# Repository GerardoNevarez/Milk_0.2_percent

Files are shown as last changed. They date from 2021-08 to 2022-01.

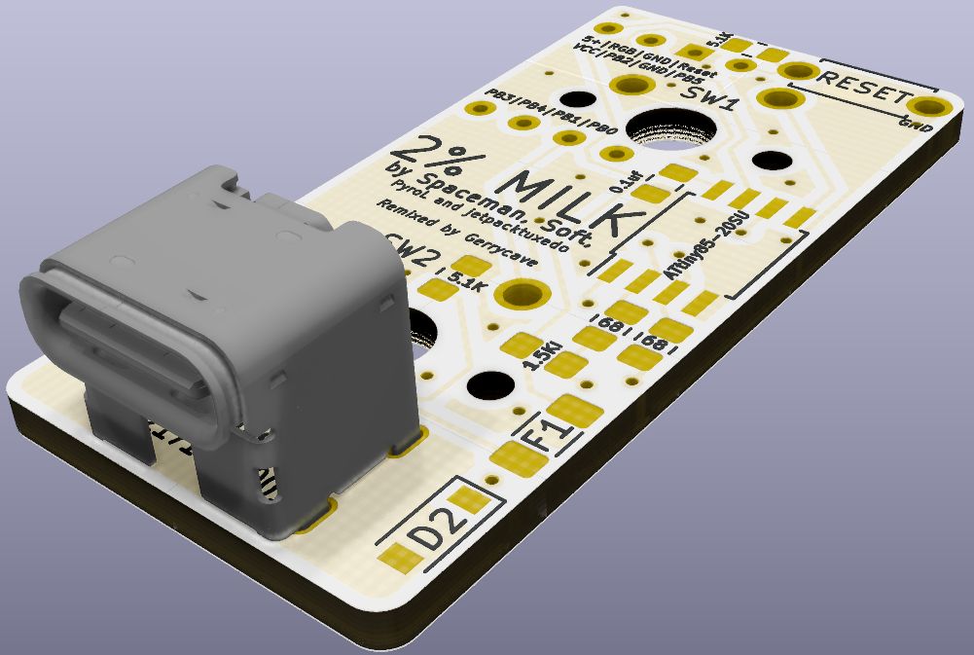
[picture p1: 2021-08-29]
milk-3D-render.jpg

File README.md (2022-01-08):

# Milk 0.2 percent

Remix from the [2% Milk](https://github.com/Spaceboards/SpaceboardsHardware/blob/master/Keyboards/2%25%20Milk/milk_kicad.zip) by Spaceman

# BOM

- 1 - Molex 2171800001 USB-C connector [Mouser](https://www.mouser.com/ProductDetail/Molex/217180-0001?qs=DRkmTr78QAS4XYOWSgPndA%3D%3D)
- 1 - SOIC-8 ATtiny85 - [ATTINY85-20SU](https://www.mouser.com/ProductDetail/Microchip-Technology-Atmel/ATTINY85-20SU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) 
- 1 - 0805 0.1uF ceramic cap
- 1 - 0805 4.7uF ceramic cap
- 1 - 0805 1.5k omh resistor
- 2 - 0805 5.1k omh resistors
- 2 - 0805 68 omh resistors
- 1 - 1206 500ma PolyFuse
- 2 - 0805 3.6V Zener diodes
- 1 - (optional) 6x3mm THT temporary push switch (Reset)
- 2 - (optional) 1515 RGB leds - SK6805-EC-15 [Adafruit](https://www.adafruit.com/product/4492)

Use the front and back PCB renders, to locate the location for the parts

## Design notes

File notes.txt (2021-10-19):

1-RST button
2-PB3 header
3-PB4 header
4-GND - rst button, SW1,SW1 Pad2 NW, RGB header
5-SW1-pad1-NE
6-SW2-pad1-NE
7-RGB header
8-5V RGB header

switch holes  2/1.3mm

 1.524  / 0.8128
 
 0.762  mm sockets

 1.397

 36.69   17.42 plate hole
 
 42.55   23    box holes

5mm  to window
7.95   window height

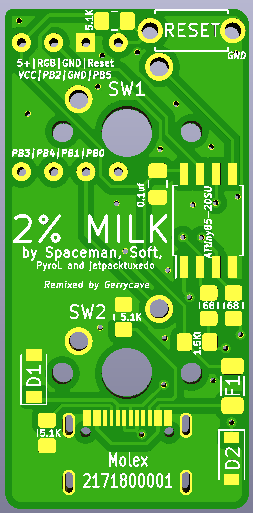
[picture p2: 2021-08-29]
milk-front.png

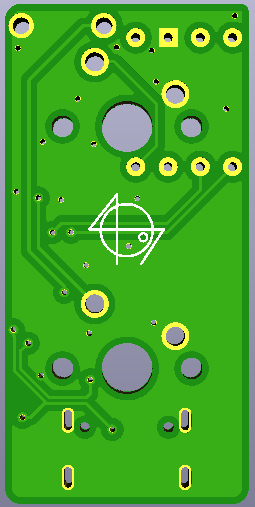
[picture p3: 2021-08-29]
milk-back.png

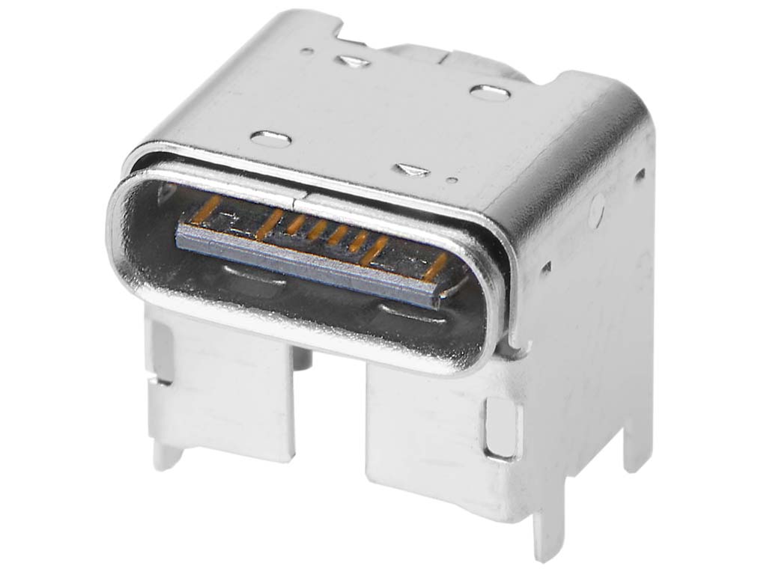
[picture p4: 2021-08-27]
Molex_data/2171800001_hires.jpg

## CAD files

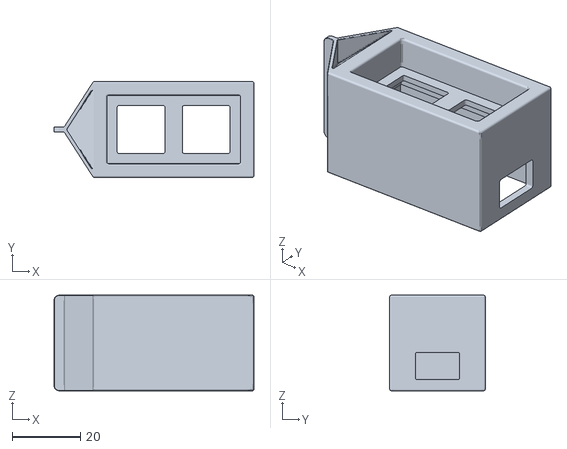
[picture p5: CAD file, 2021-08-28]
milk_case.stl
58.6 x 28.0 x 28.0

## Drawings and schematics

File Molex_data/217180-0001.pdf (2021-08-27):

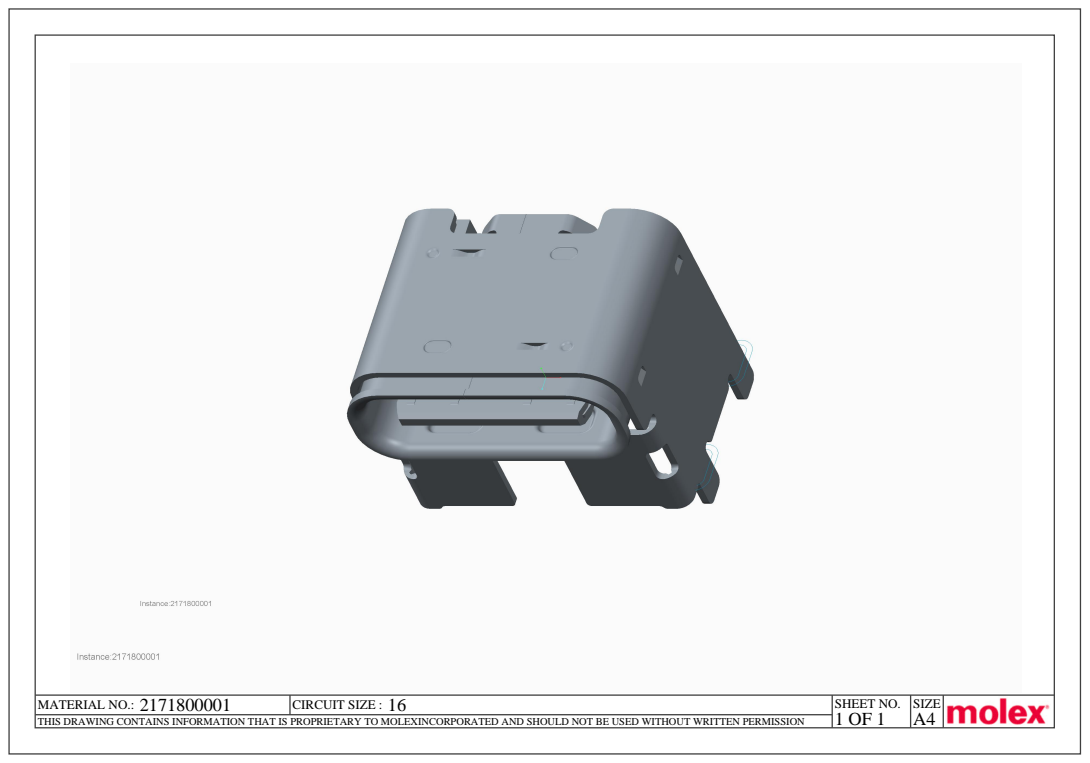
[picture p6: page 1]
MATERIAL NO.: 2171800001; CIRCUIT SIZE : 16; SHEET NO.; SIZE

THIS DRAWING CONTAINS INFORMATION THAT IS PROPRIETARY TO MOLEXINCORPORATED AND SHOULD NOT BE USED WITHOUT WRITTEN PERMISSION

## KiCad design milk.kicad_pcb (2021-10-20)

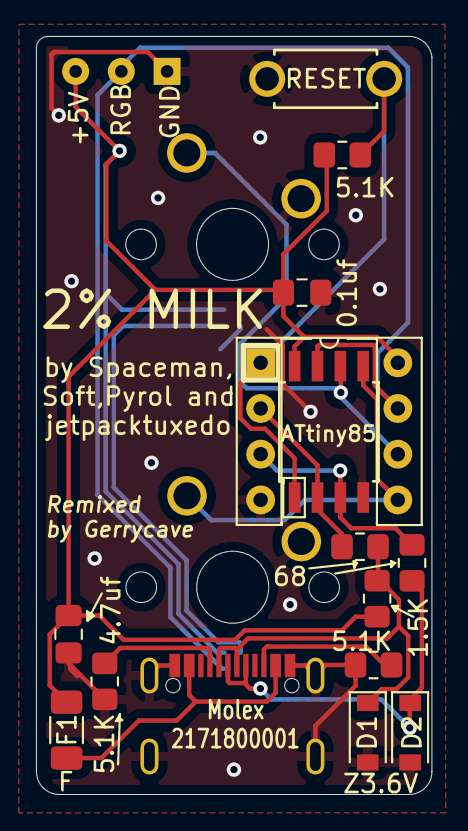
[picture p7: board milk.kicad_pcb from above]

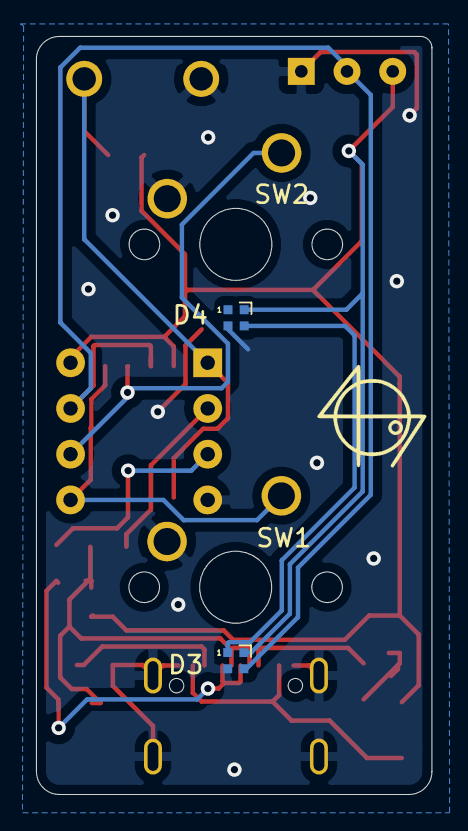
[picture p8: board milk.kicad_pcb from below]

Board: 2 copper layers, 22.0 x 42.1 mm, 20 parts (4 on the bottom side), 14 nets.

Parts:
C1: 0.1uf; C_0805_2012Metric_Pad1.18x1.45mm_HandSolder
C2: 4.7uf; C_0805_2012Metric_Pad1.18x1.45mm_HandSolder
D1, D2: 3.6V; D_SOD-123
D3, D4: SK6805; LED_SK6812_EC15_1.5x1.5mm
F1: Polyfuse; R_1206_3216Metric_Pad1.30x1.75mm_HandSolder
J1: USB_C_Receptacle_USB2.0; Molex_2171800001
J2: RGB; PinHeader_1x03_P2.54mm_Vertical
J3: DIP-8 Socket; DIP-8_W7.62mm_Socket
R1, R2, R6: 5.1K; R_0805_2012Metric_Pad1.20x1.40mm_HandSolder
R3, R4: 68; R_0805_2012Metric_Pad1.20x1.40mm_HandSolder
R5: 1.5K; R_0805_2012Metric_Pad1.20x1.40mm_HandSolder
SW1, SW2: SW_Push; SW_Cherry_MX_1.00u_PCB-2mm
SW3: SW_Push_Reset; ResetSW_1side
U1: ATtiny85-20SU; SOIJ-8_5.3x5.3mm_P1.27mm

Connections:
+5V: C1.1, C2.2, D3.4, D4.4, F1.1, J2.3, J3.8, R5.1, R6.2, U1.8
D+: D2.1, J1.A6, J1.B6, R4.2
D-: D1.1, J1.A7, J1.B7, R3.2, R5.2
GND: C1.2, C2.1, D1.2, D2.2, D3.2, D4.2, J1.A1, J1.B1, J1.S1, J2.1, J3.4, R1.1, R2.1, SW1.2, SW2.2, SW3.2, U1.4
unnamed: D3.1, D4.3
unnamed: J1.A5, R1.2
unnamed: J1.B5, R2.2
PB0: J3.5, SW1.1, U1.5
PB1: J3.6, SW2.1, U1.6
PB3: J3.2, R3.1, U1.2
PB4: J3.3, R4.1, U1.3
RGB: D3.3, J2.2, J3.7, U1.7
RST: J3.1, R6.1, SW3.1, U1.1
VCC: F1.2, J1.A4, J1.B4

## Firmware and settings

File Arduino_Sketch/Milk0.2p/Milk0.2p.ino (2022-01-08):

#include "DigiKeyboard.h"
#include <WS2811.h>

#define RGB_PIN 2

// DEFINE_WS2811_FN(NAME, PORT, PIN) 
DEFINE_WS2811_FN(WS2811RGB, PORTB, RGB_PIN)

RGB_t rgb[2]; 

void setPixel(uint16_t i, uint8_t r, uint8_t g, uint8_t b){
  rgb[i].r=r;
  rgb[i].g=g;
  rgb[i].b=b;
}
void updatePixels(){
  WS2811RGB(rgb, ARRAYLEN(rgb));
}

#define KEY_KPENTER 0x58 // Keypad ENTER
#define KEY_KP1 0x59 // Keypad 1 and End
#define KEY_KP2 0x5a // Keypad 2 and Down Arrow
#define KEY_KP3 0x5b // Keypad 3 and PageDn
#define KEY_KP4 0x5c // Keypad 4 and Left Arrow
#define KEY_KP5 0x5d // Keypad 5
#define KEY_KP6 0x5e // Keypad 6 and Right Arrow
#define KEY_KP7 0x5f // Keypad 7 and Home
#define KEY_KP8 0x60 // Keypad 8 and Up Arrow
#define KEY_KP9 0x61 // Keypad 9 and Page Up
#define KEY_KP0 0x62 // Keypad 0 and Insert
#define KEY_KPDOT 0x63 // Keypad . and Delete4

#define KEY_UP_WAIT 1

void wait_until_no_button_down();

bool pin0();
bool pin1();

void setup() {

  // RGB pin
  pinMode(RGB_PIN, OUTPUT);

  // Switch 1
  pinMode(0, INPUT_PULLUP);

  // Switch 2
  pinMode(1, INPUT_PULLUP);
  
  // Force USB connection
  DigiKeyboard.sendKeyStroke(0);
  DigiKeyboard.update();
}

void loop() {

  setPixel(0, 255,   0, 0); //set first  pixel (zero indexed) to red
  setPixel(1,   0, 255, 0); //set second pixel (zero indexed) to green
  updatePixels(); //show the change
  
  // this is generally not necessary but with some older systems it seems to
  // prevent missing the first character after a delay:
  DigiKeyboard.sendKeyStroke(0);

  bool p0, p1 = false;

  p0 = pin0();
  p1 = pin1();

  if (p0){
    DigiKeyboard.sendKeyStroke(KEY_KP7);
  }
  
  if (p1){
    DigiKeyboard.sendKeyStroke(KEY_KP8);
  }

  if (p1 || p0){
    wait_until_no_button_down();
  }


}

bool pin0(){
  return digitalRead(0) == LOW;
}

bool pin1(){
  return digitalRead(1) == LOW;
}

void wait_until_no_button_down(){
   bool button1, button2;
  do{
    DigiKeyboard.delay(KEY_UP_WAIT);
    button1 = pin0();
    button2 = pin1();
  } while (button1 || button2) ;
}

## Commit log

2021-08-27 Initial import from SpaceboardsHardware
    https://github.com/Spaceboards/SpaceboardsHardware/blob/master/Keyboards/2%25%20Milk/milk_kicad.zip
    [milk.kicad_pcb, milk.sch]
2021-08-27 Add footprint and engineering data for Molex 2171800001 USB-C connector
2021-08-27 initial schematic and layout (fails drc)
    [milk.kicad_pcb, milk.sch]
2021-08-28 DRC ok
    [milk.kicad_pcb]
2021-08-28 Add programming headers (all over the place... yes)
    [milk-B_Cu.gbr, milk-B_Mask.gbr, milk-B_Paste.gbr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]
2021-08-28 Final gerber, rendered images
    [milk-B_Cu.gbr, milk-B_Mask.gbr, milk-B_Paste.gbr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]
2021-08-28 Add case STL from OG repo
    [milk_case.stl]
2021-08-29 Fix pogo pin tht holes
    [milk-B_Cu.gbr, milk-B_Mask.gbr, milk-B_Paste.gbr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]
2021-08-29 Add pull up resistor for Reset/PB5
    [milk-B_Cu.gbr, milk-B_Mask.gbr, milk-B_Paste.gbr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]
2021-08-30 Change programming header for a DIP-8 package, compatible with ATtiny85-20PU
    [milk-B_Cu.gbr, milk-B_Mask.gbr, milk-B_Paste.gbr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]
2021-10-19 Redo routing, add unsolderable RGB leds
    [milk-B_Cu.gbr, milk-B_Mask.gbr, milk-B_Paste.gbr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]
2021-10-19 Fix RGB header orientation
    [milk-B_Cu.gbr, milk-B_Mask.gbr, milk-B_Paste.gbr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]
2021-10-20 corrections to +5V line, fine-tunning tracing
    [milk-B_Cu.gbr, milk-B_Mask.gbr, milk-B_Paste.gbr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]
2022-01-08 Add Arduino sketch
2022-01-08 more BOM details
